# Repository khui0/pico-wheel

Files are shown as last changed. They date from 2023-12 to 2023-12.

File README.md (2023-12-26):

# Pico Wheel

DIY sim racing wheel using a Raspberry Pi Pico and an AS5600 magnetic encoder

pico-wheel

## Parts list

- Pi Pico (or Pico W)
- Micro USB cable
- [AS5600 magnetic encoder](https://www.amazon.com/MELIFE-Magnetic-Induction-Measurement-Precision/dp/B0B8ZDSH9Z/)
- 4x2mm diametric magnet
- [2x 6x6x4.3mm momentary push button](https://www.amazon.com/4-3mm-Momentary-Tactile-Button-Switch/dp/B0796QL57S/)
- 2x 608ZZ bearings
- 24x M3x8 bolts
- 2-4x M3x4 bolts
- 2x M3x20 bolts
- 2x M3x10 bolts
- 7x M3 nuts
- 1x M3x25 bolt
- 2-4x M2x4 bolts
- ~6x "Rainbow Loom" bands

## Firmware

The firmware is written in Arduino using the Arduino IDE and [arduino-pico](https://github.com/earlephilhower/arduino-pico)

The following libraries are used:

- [RobTillaart/AS5600](https://github.com/RobTillaart/AS5600)
- [benjaminaigner/Joystick](https://github.com/benjaminaigner/Joystick)

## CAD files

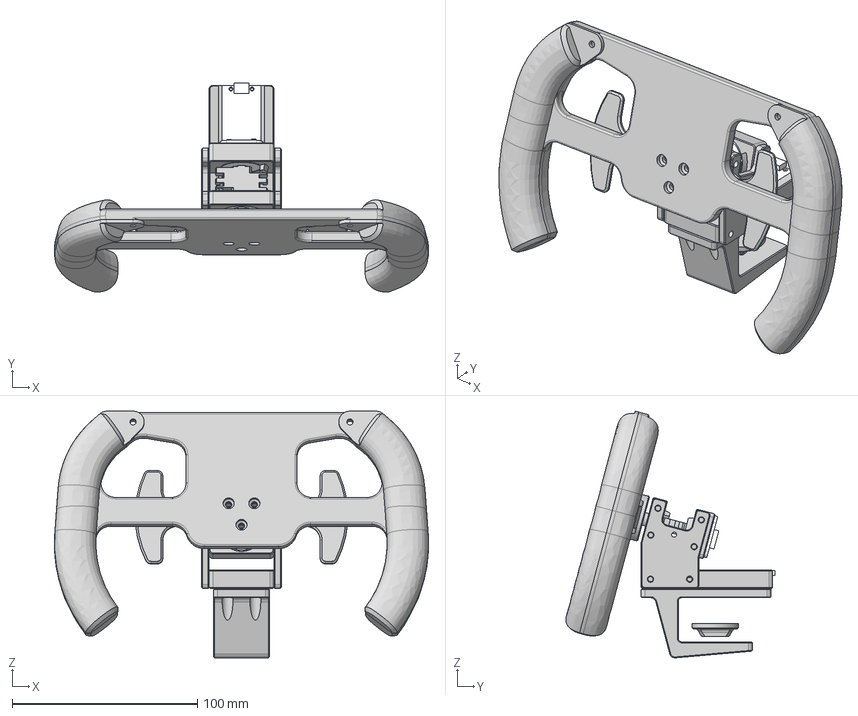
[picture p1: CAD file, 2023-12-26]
model/Pico Wheel v91.step
202.0 x 113.0 x 133.3 mm
Pi Pico
AS5600
BRACKET
F_MOUNT
R_MOUNT
608ZZ x 2
SHAFT
WHEEL_MOUNT
PADDLES
PADDLES(Mirror)
CLAMP_PAD

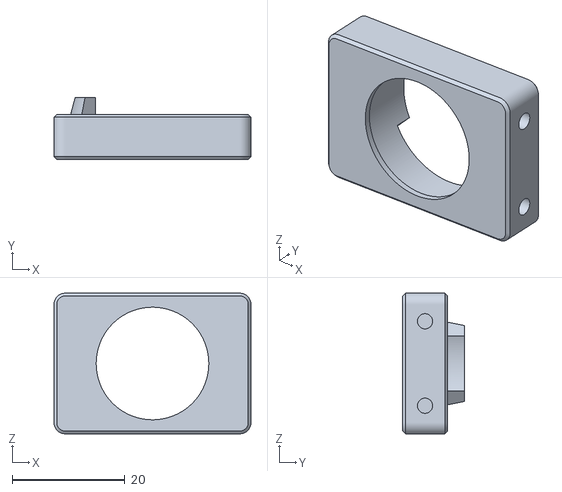
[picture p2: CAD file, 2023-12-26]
stl/F_MOUNT.stl
35.0 x 11.0 x 25.0

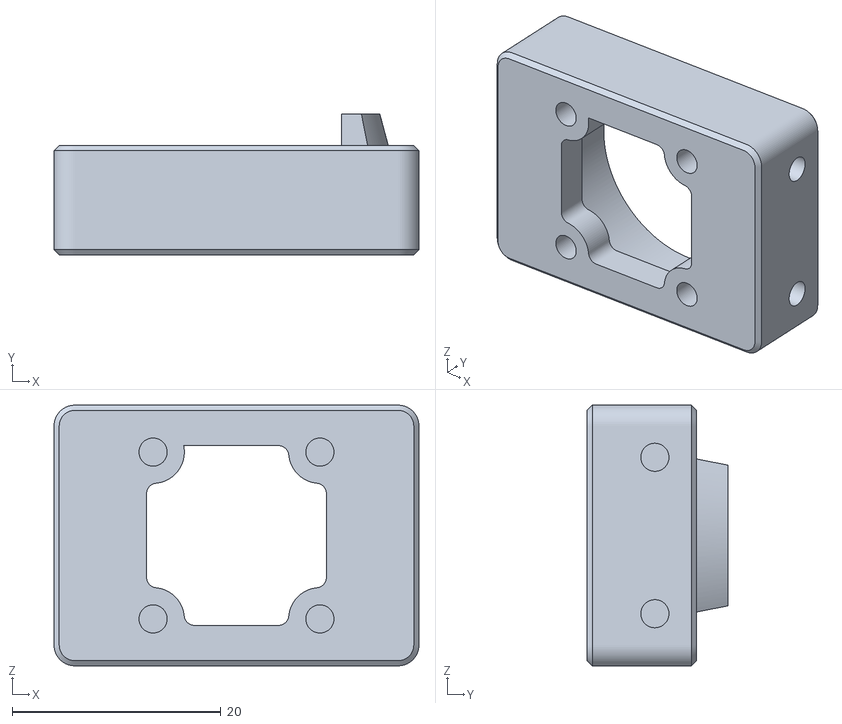
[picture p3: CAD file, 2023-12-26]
stl/R_MOUNT.stl
35.0 x 13.5 x 25.0

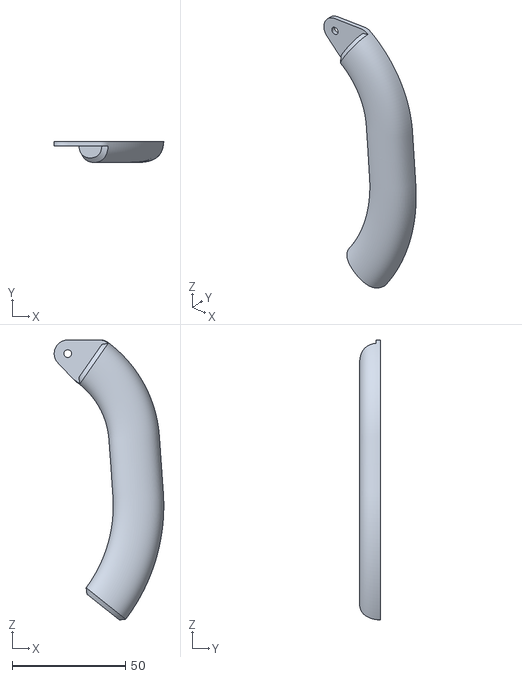
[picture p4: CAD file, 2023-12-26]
stl/GRIP_R.stl
48.4 x 9.25 x 123.7

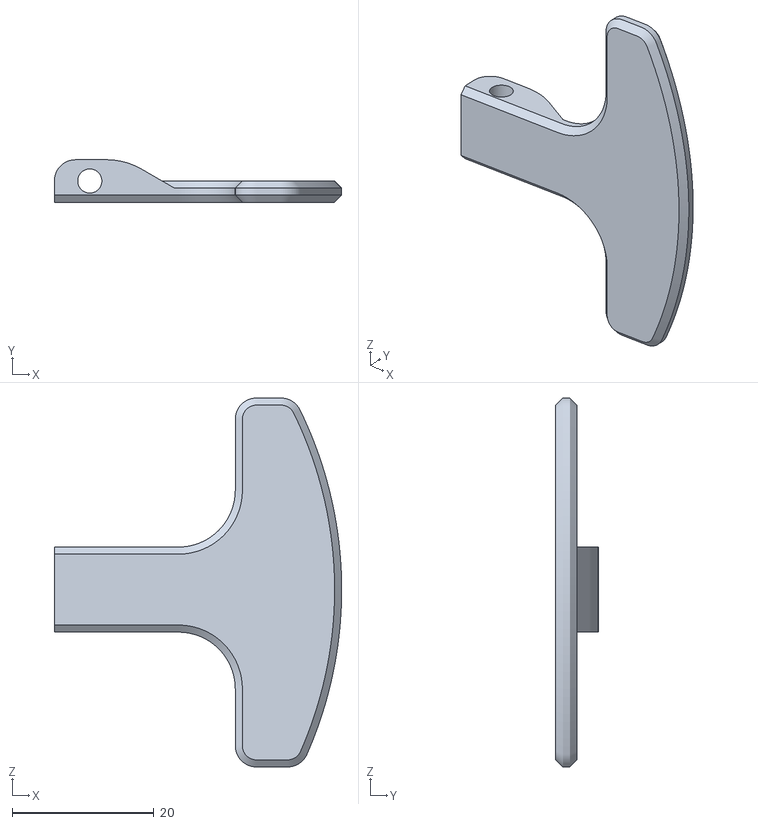
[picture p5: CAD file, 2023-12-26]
stl/PADDLE_L.stl
40.5 x 6.00 x 52.0

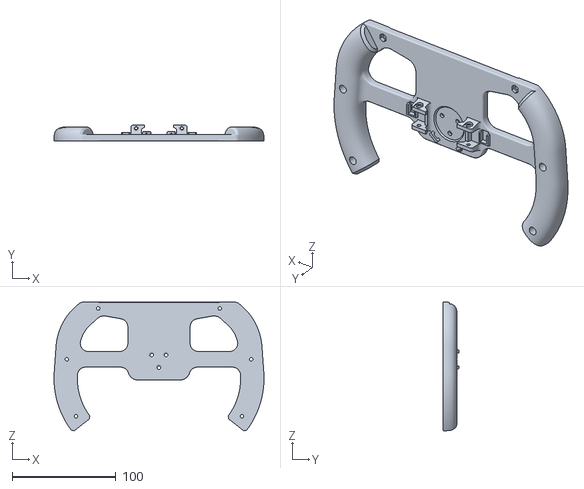
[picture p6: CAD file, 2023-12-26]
stl/STEERING_WHEEL.stl
202.1 x 15.0 x 123.8

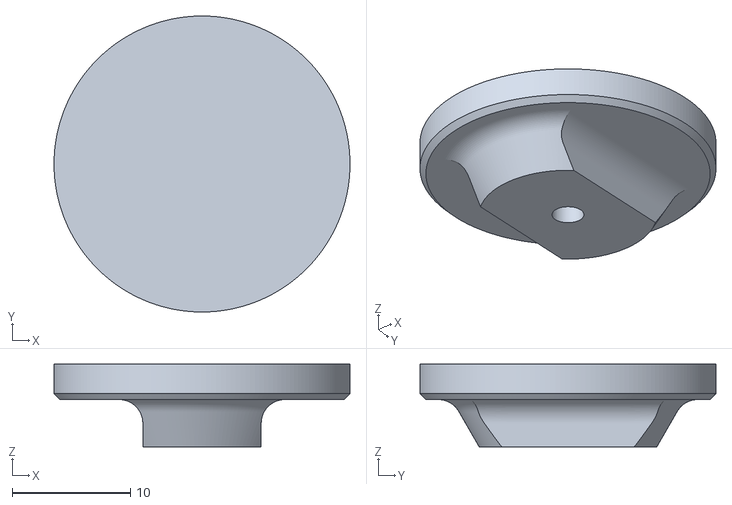
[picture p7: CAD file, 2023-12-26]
stl/CLAMP_PAD.stl
25.0 x 25.0 x 7.00

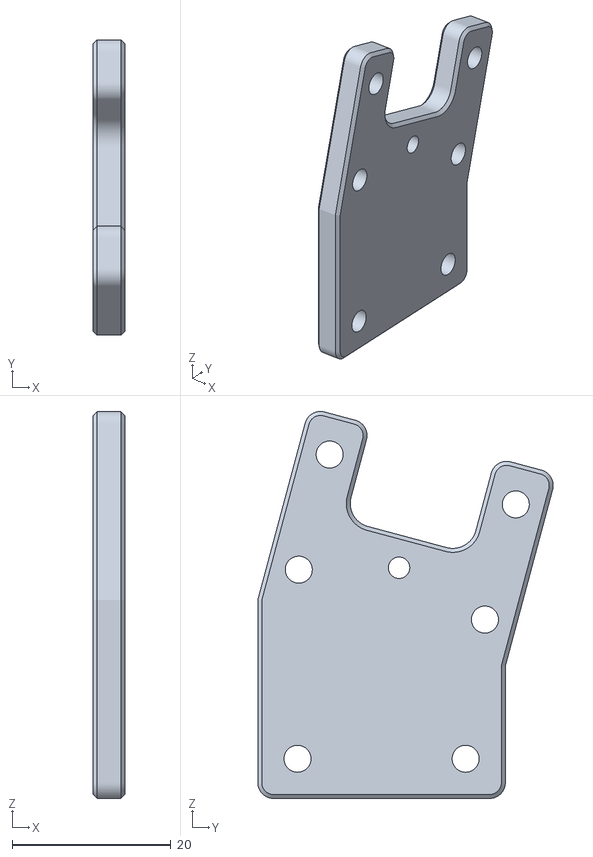
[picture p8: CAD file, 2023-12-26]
stl/BRACKET.stl
4.00 x 37.2 x 48.7

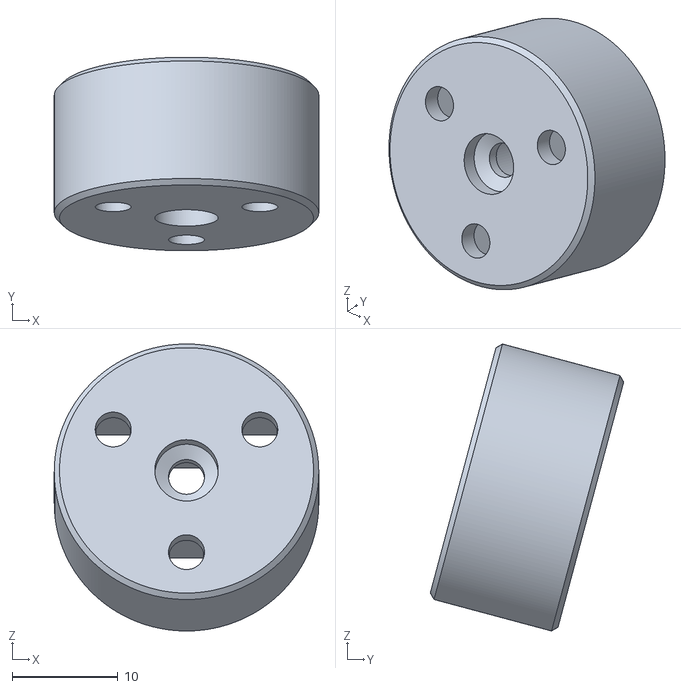
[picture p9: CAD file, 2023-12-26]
stl/WHEEL_MOUNT.stl
25.0 x 18.3 x 27.1

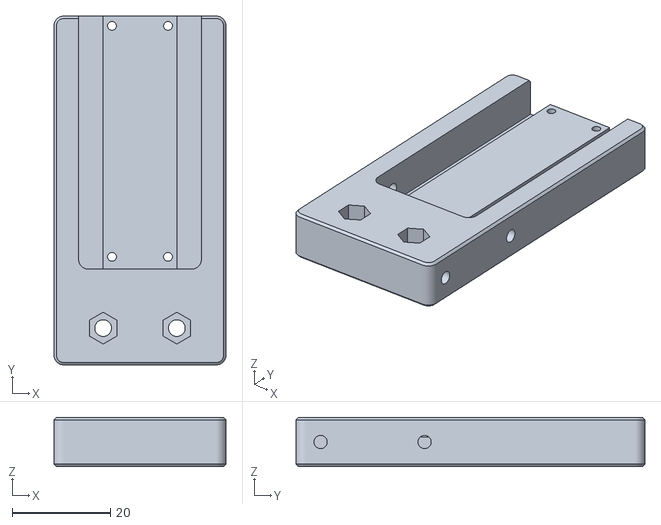
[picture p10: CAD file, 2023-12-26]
stl/BASE.stl
35.0 x 71.0 x 10.0

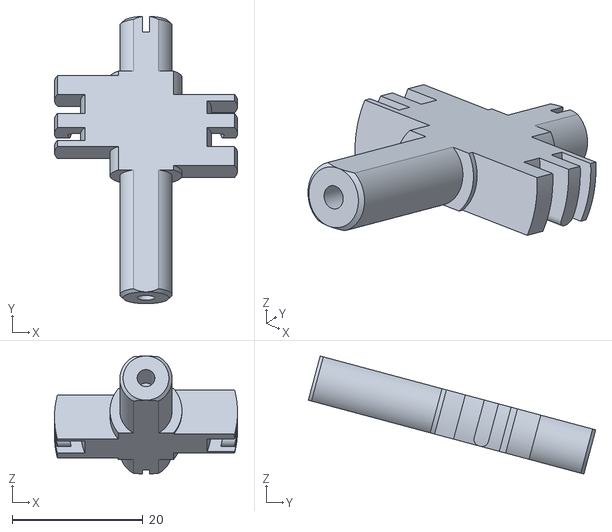
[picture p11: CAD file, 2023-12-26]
stl/SHAFT.stl
28.0 x 44.0 x 18.0

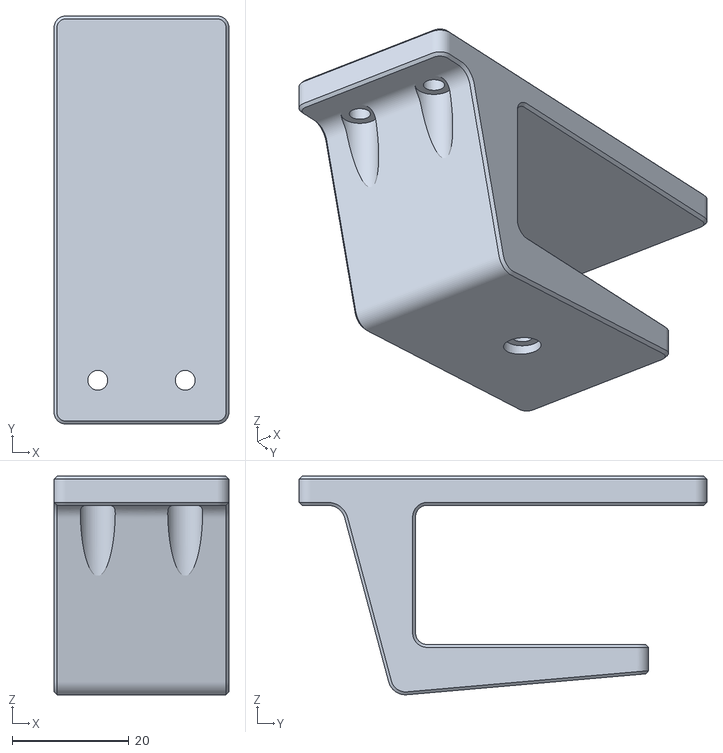
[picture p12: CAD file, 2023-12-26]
stl/DESK_MOUNT.stl
30.0 x 70.0 x 37.5

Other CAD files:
stl/GRIP_L.stl
stl/PADDLE_R.stl

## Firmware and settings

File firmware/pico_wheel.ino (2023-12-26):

#include "AS5600.h"
#include "Wire.h"
#include <Joystick.h>

AS5600 as5600;

const int DEBUG_MODE_PIN = 15;
const int PADDLE_RIGHT = 0;
const int PADDLE_LEFT = 1;

int32_t wheel_range = 270 / AS5600_RAW_TO_DEGREES;
int32_t zero_angle;

int paddle_right_position = 0;
int paddle_left_position = 0;

int32_t reset_start;
int8_t reset_triggered = 0;
int8_t paddles_held = 0;

void setup() {
  pinMode(LED_BUILTIN, OUTPUT);
  pinMode(DEBUG_MODE_PIN, INPUT_PULLUP);
  pinMode(PADDLE_RIGHT, INPUT_PULLUP);
  pinMode(PADDLE_LEFT, INPUT_PULLUP);

  Serial.begin(115200);
  Joystick.begin();

  // Initialize AS5600
  as5600.begin(4);
  as5600.setDirection(AS5600_CLOCK_WISE);
  // Breaks if missing for some reason
  as5600.isConnected();

  // Set zero position
  zero_angle = as5600.getCumulativePosition();
}

void loop() {
  int32_t degrees = as5600.getCumulativePosition() - zero_angle;
  int32_t limited = constrain(degrees, -wheel_range / 2, wheel_range / 2);

  // if (!digitalRead(PADDLE_RIGHT)) {
  //   Joystick.button(1, true);
  // } else {
  //   Joystick.button(1, false);
  // }

  // if (!digitalRead(PADDLE_LEFT)) {
  //   Joystick.button(2, true);
  // } else {
  //   Joystick.button(2, false);
  // }

  // Zero wheel position by holding both paddles for 3s
  if (!digitalRead(PADDLE_RIGHT) && !digitalRead(PADDLE_LEFT)) {
    if (paddles_held == 0) {
      paddles_held = 1;
      reset_start = millis();
    } else {
      int32_t elapsed = millis() - reset_start;
      if (elapsed > 3000 && reset_triggered == 0) {
        reset_triggered = 1;
        // Flash LED
        digitalWrite(LED_BUILTIN, HIGH);
        delay(500);
        digitalWrite(LED_BUILTIN, LOW);
        // Zero wheel position
        zero_angle = as5600.getCumulativePosition();
      }
    }
  } else {
    if (paddles_held == 1) {
      paddles_held = 0;
      reset_triggered = 0;
    }
  }

  // Virtual accelerator pedal
  if (!digitalRead(PADDLE_RIGHT)) {
    paddle_right_position += 2;
  } else {
    paddle_right_position -= 10;
  }
  paddle_right_position = constrain(paddle_right_position, 0, 1023);
  Joystick.Y(paddle_right_position);

  // Virtual brake pedal
  if (!digitalRead(PADDLE_LEFT)) {
    paddle_left_position += 5;
  } else {
    paddle_left_position -= 10;
  }
  paddle_left_position = constrain(paddle_left_position, 0, 1023);
  Joystick.Z(paddle_left_position);

  if (digitalRead(DEBUG_MODE_PIN)) {
    // Map degrees to joystick
    int16_t target = map(limited, -wheel_range / 2, wheel_range / 2, 0, 1023);
    Joystick.X(target);
  } else {
    Serial.print(zero_angle);
    Serial.print("\t");
    Serial.print(degrees);
    Serial.print("\t");
    Serial.print(limited);
    Serial.println();
  }
}
